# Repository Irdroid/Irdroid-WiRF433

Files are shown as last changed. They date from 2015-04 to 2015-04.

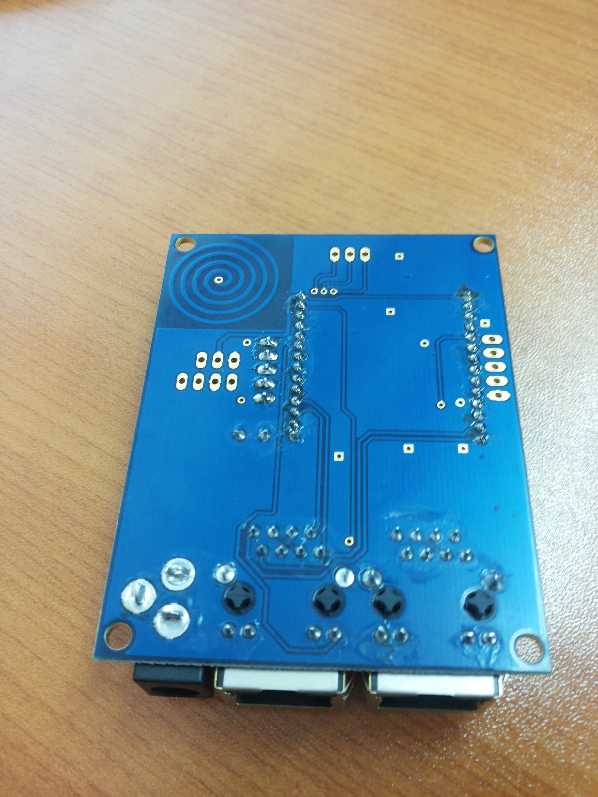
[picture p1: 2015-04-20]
Documents/Pictures & Screenshots/Irdroid-Wirf433-3.jpg

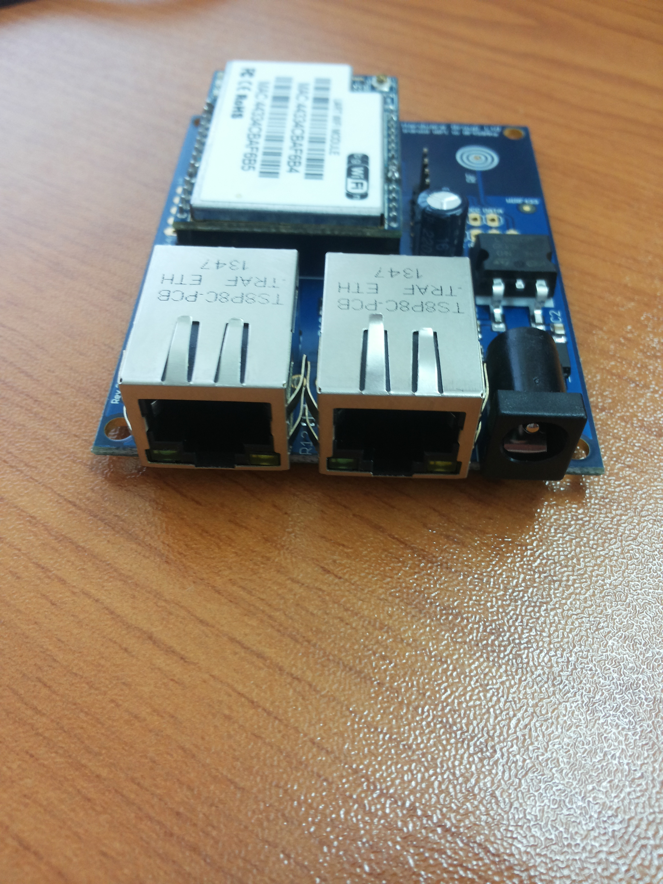
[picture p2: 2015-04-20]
Documents/Pictures & Screenshots/Irdroid-WiRF433-2.jpg

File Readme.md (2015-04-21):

#Irdroid WiRF433 - Single Board Linux Computer, Designed by Hardwate Group Ltd.
------------------------------------------------------------------------------
Irdroid WiRF433 is open source software and open source hardware, low cost starting
from USD 38 Linux Industrial grade single board computer with GPIOs capable to operate 
-25 - +85C

The Irdroid WiRF433 SBC is designed with the Ralink RT5350 SoC, 32Mbytes of RAM and 4 Mbytes of Flash.
The Irdroid WiRF433 board is designed with 2 ethernet ports, therefore the board can be 
used for routing. 

All the GPIOs of the RT5350 Soc are available on the WiRF433 board pin headers. The Irdroid WiRF433
comes also with a RF433MHZ RF module which allows for controlling IoT Remote control switches, light bulbs
and sockets operating at 433.9Mhz.

Irdroid WiRF433 is completely open source - including hardware and software, this means you have 
access to all CAD files and sources and you can reuse them for your own personal or commercial project.
There are NO restrictions to manufacture and sell these board for your own use or resale.

###Main Features:
- Mips Architecture CPU @360Mhz
- 32 Mbytes of SDRAM
- 4 Mbyets of FLASH memory
- 1 USB 2.0 HOST Port
- 1-SPI, 1-I2C , and on I2S (AUDIO)
- WiFi 802.11b/g/n interface
- 2 Ethernet interfaces 1WAN and 1LAN
- RF433 RF Remote control interface with onboard Antenna

The Irdroid WiRF433 SBC comes with preinstalled uboot bootloader and OpenWRT Linux distribution, which includes
also IoT remote control applications and software like RCSwitch for controlling RC 433.9Mhz remote control
switches and a Mobile HTML5 web application , configured for work with the RC switches, which gives the possibility to add unlimited number of RCSwitches

###APPLICATIONS:
- Home Automation Development Computer. The Open Source apps like LIRC,RCSwitch and serial web proxy will allow you to rapidly and easyly build Home Automation Systems
- IoT Development Computer. With its available interfaces, you can turn Irdroid WiRF433 into a IoT main unit, and you will be able to control RC Switches, RC Lights and RC Sockets
- Internet Router with IoT capabilities - The OpenWRT open source Linux distributions will allow you to easyly create one
- Inexpensive PLC with the open source protocols, available on the Internet.

###WEB RESOURCES:
- http://www.irdroid.com - The Irdroid project website, where Irdroid WiRF433 board info is hosted
- http://github.com/irdroid - Project's Github repositories.
- http://www.irdroid.eu/product/irdroid-wifi-rf433mhz-development-computer/ - Currently you can purchase a sample board from irdroid.eu for 38$

###HARDWARE
The Hardware project is released under the Creative Commons Attribution-Share Alike 3.0 United States License. You may reproduce it for both your own personal use, and for commertial use. You will have to provide a link to the original creator of the project http://www.irdroid.com on any documentation or website.
You may also modify the files, but you must then release them as well under the same terms.Credit can be attributed through a link to the creator website: http://www.irdroid.com

###SOFTWARE
The Irdroid WiRF433 Development board comes with preinstalled uboot bootloader and the OpenWRT Linux distribution. The board also comes with the following preinstalled applications:
- RCSwitch for controlling RF433Mhz remote control sockets, lights and switches
- Web Based HTML5 Interface for RCSwitch

The software is released under GPL.

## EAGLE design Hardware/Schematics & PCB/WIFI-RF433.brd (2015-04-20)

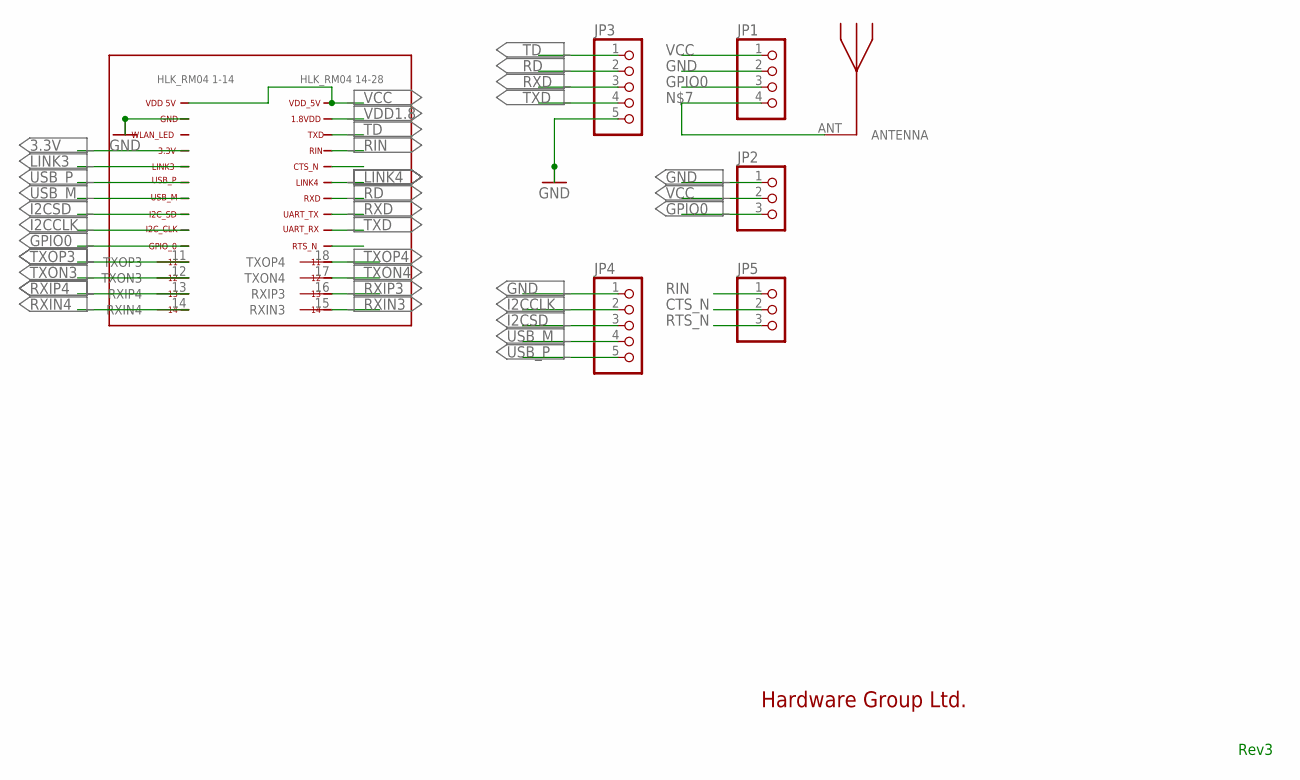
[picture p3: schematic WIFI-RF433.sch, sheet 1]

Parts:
JP1: PINHD-1X4; 1X04
JP2, JP5: PINHD-1X3; 1X03
JP3, JP4: PINHD-1X5; 1X05
U$4: 433MHZ
U$8: 1X10

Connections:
3.3V: U$8.4 (3.3VDD)
CTS_N: JP5.2, U$8.24 (CTS_N)
GND: JP1.2, JP2.1, JP3.5, JP4.1, U$8.2 (GND); also elsewhere on the board
GPIO0: JP1.3, JP2.3, U$8.10 (GPIO_0)
I2CCLK: JP4.2, U$8.9 (I2C_CLK)
I2CSD: JP4.3, U$8.8 (I2C_SD)
LINK3: U$8.5 (LINK3); also elsewhere on the board
LINK4: U$8.23 (LINK4); also elsewhere on the board
unnamed: JP1.4, U$4.ANT
RD: JP3.2, U$8.22 (RXD)
RIN: JP5.1, U$8.25 (RIN)
RTS_N: JP5.3, U$8.19 (RTS_N)
RXD: JP3.3, U$8.21 (UART_TX)
RXIN3: U$8.15 (RXIN3); also elsewhere on the board
RXIN4: U$8.14 (RXIN4); also elsewhere on the board
RXIP3: U$8.16 (RXIP3); also elsewhere on the board
RXIP4: U$8.13 (RXIP4); also elsewhere on the board
TD: JP3.1, U$8.26 (TXD)
TXD: JP3.4, U$8.20 (UART_RX)
TXON3: U$8.12 (TXON3); also elsewhere on the board
TXON4: U$8.17 (TXON4); also elsewhere on the board
TXOP3: U$8.11 (TXOP3); also elsewhere on the board
TXOP4: U$8.18 (TXOP4); also elsewhere on the board
USB_M: JP4.4, U$8.7 (USB_M)
USB_P: JP4.5, U$8.6 (USB_P)
VCC: JP1.1, JP2.2, U$8.1 (VDD_5V), U$8.28 (VDD_5V_); also elsewhere on the board
VDD1.8: U$8.27 (1.8VDD); also elsewhere on the board

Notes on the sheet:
Hardware Group Ltd.
Rev3

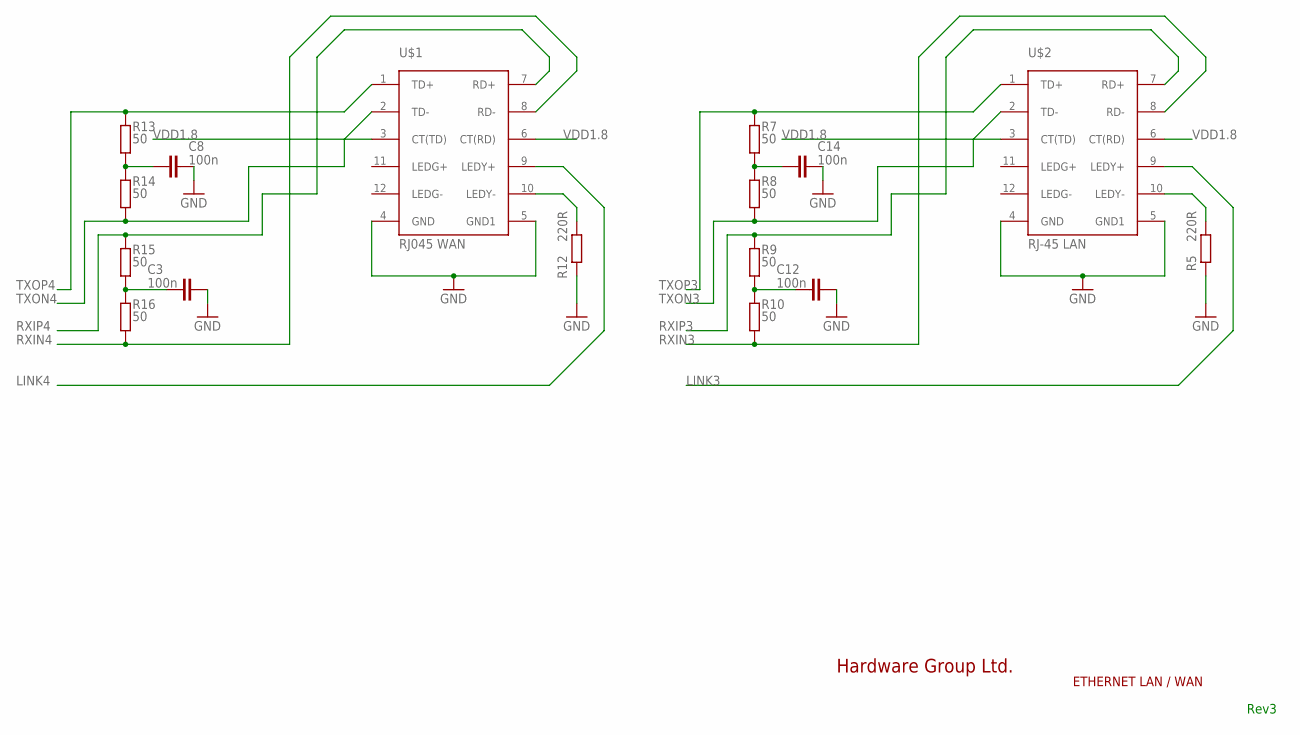
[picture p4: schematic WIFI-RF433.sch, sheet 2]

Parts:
C3, C8, C12, C14: 100n; C0805
R5, R12: 220R; R0805
R7, R8, R9, R10, R13, R14, R15, R16: 50; R0805
U$1: RJ045 WAN; MAGJACK
U$2: RJ-45 LAN; MAGJACK

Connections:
GND: C3.2, C8.2, C12.2, C14.2, R5.1, R12.1, U$1.4 (GND), U$1.5 (GND1), U$2.4 (GND), U$2.5 (GND1); also elsewhere on the board
LINK3: U$2.9 (LEDY+); also elsewhere on the board
LINK4: U$1.9 (LEDY+); also elsewhere on the board
unnamed: R5.2, U$2.10 (LEDY-)
unnamed: C3.1, R15.1, R16.2
unnamed: R12.2, U$1.10 (LEDY-)
unnamed: C8.1, R13.1, R14.2
unnamed: C14.1, R7.1, R8.2
unnamed: C12.1, R9.1, R10.2
RXIN3: R10.1, U$2.8 (RD-); also elsewhere on the board
RXIN4: R16.1, U$1.8 (RD-); also elsewhere on the board
RXIP3: R9.2, U$2.7 (RD+); also elsewhere on the board
RXIP4: R15.2, U$1.7 (RD+); also elsewhere on the board
TXON3: R8.1, U$2.2 (TD-); also elsewhere on the board
TXON4: R14.1, U$1.2 (TD-); also elsewhere on the board
TXOP3: R7.2, U$2.1 (TD+); also elsewhere on the board
TXOP4: R13.2, U$1.1 (TD+); also elsewhere on the board
VDD1.8: U$1.3 (CT(TD)), U$1.6 (CT(RD)), U$2.3 (CT(TD)), U$2.6 (CT(RD)); also elsewhere on the board

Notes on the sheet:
Hardware Group Ltd.
ETHERNET LAN / WAN
Rev3

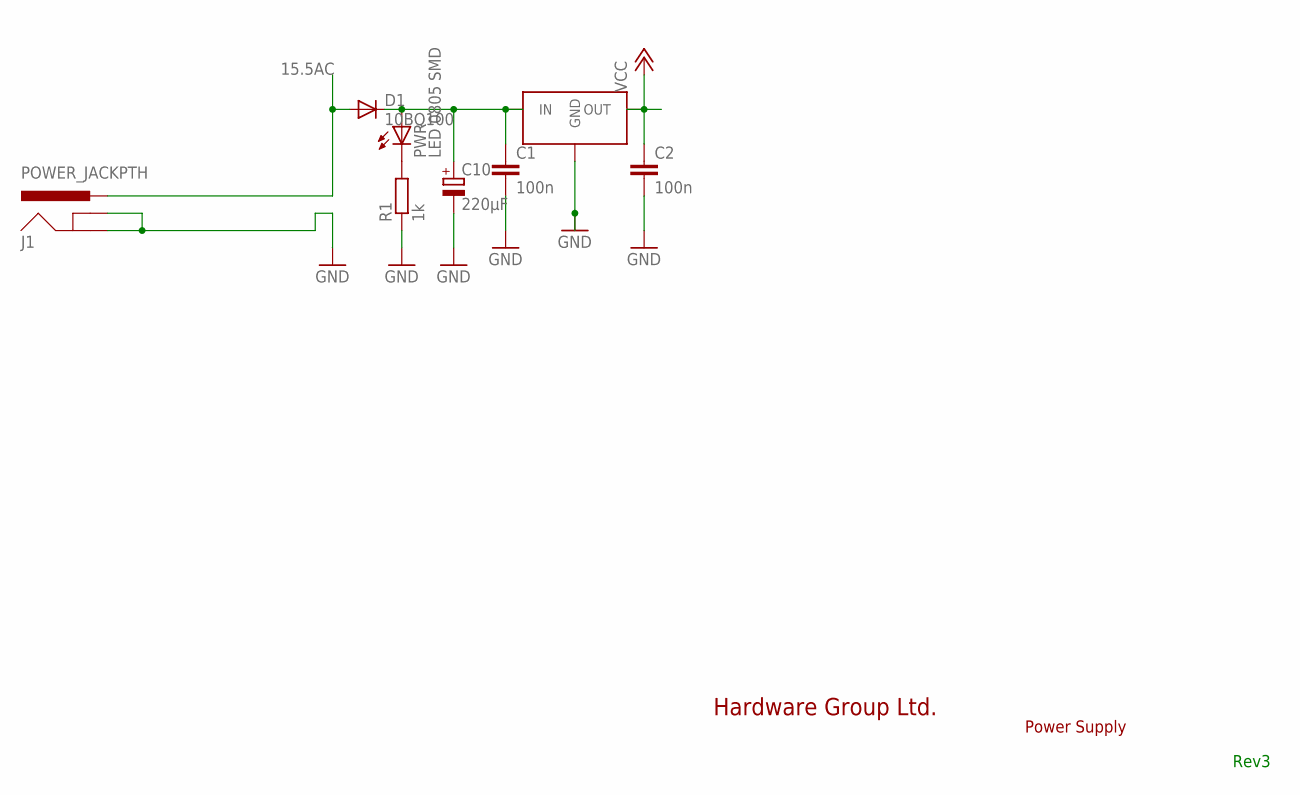
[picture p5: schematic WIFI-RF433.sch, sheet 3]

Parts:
C1, C2: 100n; C0805
C10: 220µF; E3,5-8
D1: 10BQ100; SMB
J1: POWER_JACKPTH; POWER_JACK_PTH
PWR: LED 0805 SMD; CHIP-LED0805
R1: 1k; M0805
U$3: VREG-7805-DPAK2

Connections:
15.5AC: D1.A, J1.PWR
GND: C1.2, C2.2, C10.-, J1.GND, J1.GNDBREAK, R1.1, U$3.GND; also elsewhere on the board
unnamed: PWR.C, R1.2
unnamed: C1.1, C10.+, D1.C, PWR.A, U$3.VIN (IN)
VCC: C2.1, U$3.VOUT (OUT); also elsewhere on the board

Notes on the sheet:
Hardware Group Ltd.
Power Supply
Rev3

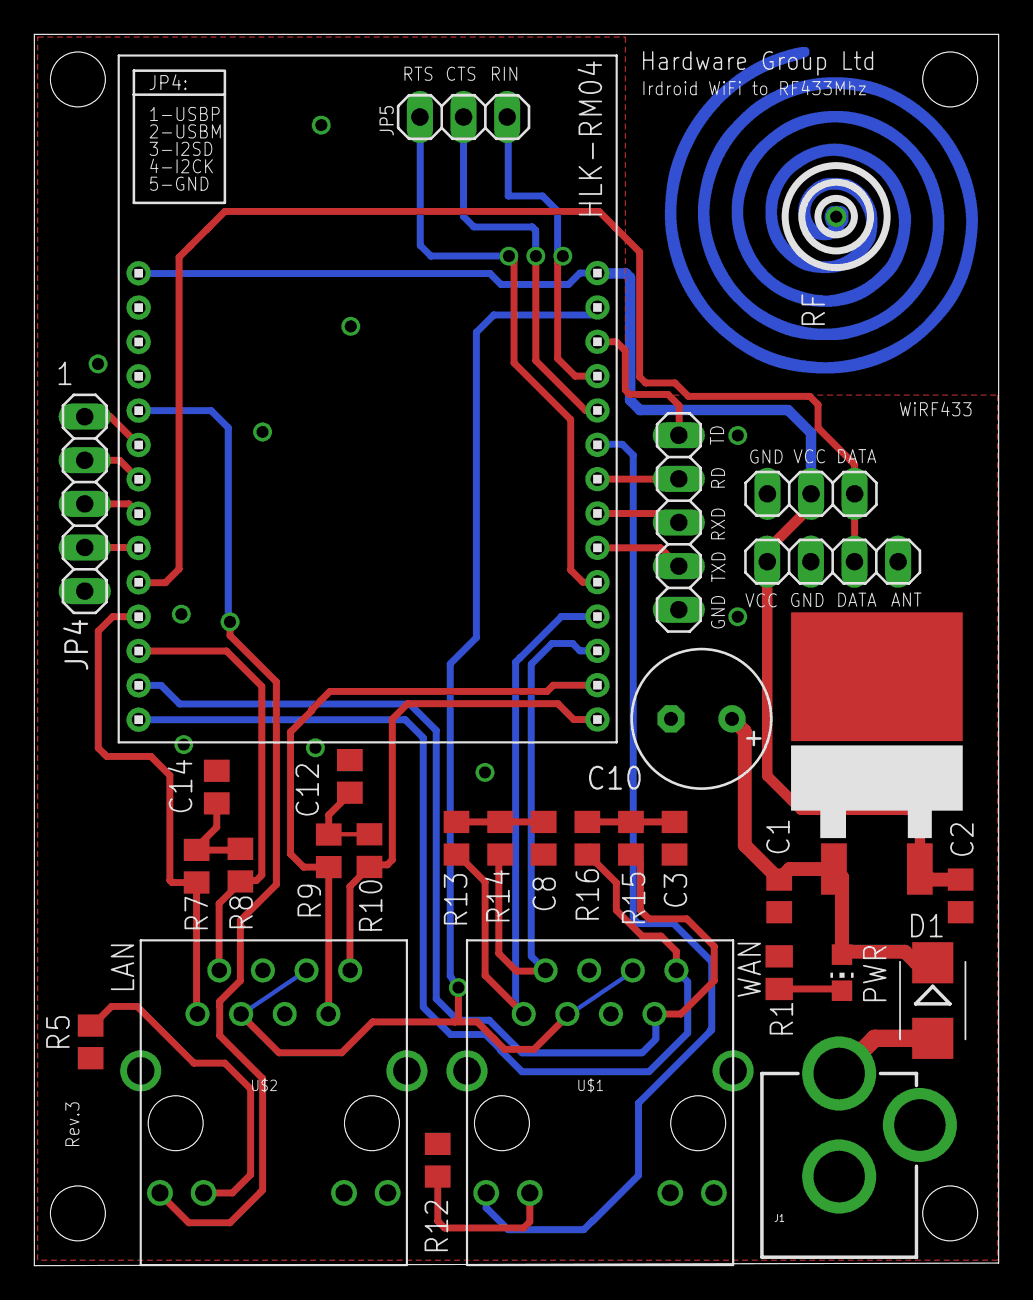
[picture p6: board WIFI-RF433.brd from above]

Board: 2 copper layers, 56.2 x 71.7 mm, 31 parts (0 on the bottom side), 35 nets.

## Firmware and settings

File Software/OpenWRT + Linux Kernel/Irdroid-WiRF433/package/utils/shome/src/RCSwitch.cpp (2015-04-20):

/*
  RCSwitch - Arduino libary for remote control outlet switches
  Copyright (c) 2011 Suat Özgür.  All right reserved.
  
  Contributors:
  - Andre Koehler / info(at)tomate-online(dot)de
  - Gordeev Andrey Vladimirovich / gordeev(at)openpyro(dot)com
  - Skineffect / http://forum.ardumote.com/viewtopic.php?f=2&t=48
  
  Project home: http://code.google.com/p/rc-switch/

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
  You should have received a copy of the GNU Lesser General Public
  License along with this library; if not, write to the Free Software
  Foundation, Inc., 51 Franklin St, Fifth Floor, Boston, MA  02110-1301  USA
*/

#include "RCSwitch.h"
#include <stdio.h>
#include <string.h>
#include <stdlib.h>
unsigned long RCSwitch::nReceivedValue = NULL;
unsigned int RCSwitch::nReceivedBitlength = 0;
unsigned int RCSwitch::nReceivedDelay = 0;
unsigned int RCSwitch::nReceivedProtocol = 0;
unsigned int RCSwitch::timings[RCSWITCH_MAX_CHANGES];
int RCSwitch::nReceiveTolerance = 60;

RCSwitch::RCSwitch() {
//  this->nReceiverInterrupt = -1;
  this->nTransmitterPin = 0;
//  RCSwitch::nReceivedValue = NULL;
//  this->setPulseLength(timer);
//  this->setRepeatTransmit(40);
//  this->setReceiveTolerance(60);
  this->setProtocol(1);
}

/**
  * Sets the protocol to send.
  */
void RCSwitch::setProtocol(int nProtocol) {
  this->nProtocol = nProtocol;
  if (nProtocol == 1){
//	  this->setPulseLength(timer);
  }
  else if (nProtocol == 2) {
//	  this->setPulseLength(650);
  }
}
void digitalWrite(int led, int state) {
FILE *f1;


f1 = fopen ("/sys/class/gpio/gpio0/value", "w");
fprintf (f1, "%d", state);
fclose (f1);
}
void pinMode(int pin, int state) {
FILE *f1;
f1 = fopen ("/sys/class/gpio/export", "w");
fprintf (f1, "%d", pin);
fclose (f1);





f1 = fopen ("/sys/class/gpio/gpio0/direction", "w");
fprintf (f1, "out");
fclose (f1);

digitalWrite(pin, 0);
}
void delayMicrosecondsHard (unsigned int howLong)
{
  struct timeval tNow, tLong, tEnd ;

  gettimeofday (&tNow, NULL) ;
  tLong.tv_sec = howLong / 1000000 ;
  tLong.tv_usec = howLong % 1000000 ;
  timeradd (&tNow, &tLong, &tEnd) ;

  while (timercmp (&tNow, &tEnd, <))
    gettimeofday (&tNow, NULL) ;
}

void delayMicroseconds (unsigned int howLong)
{
  struct timespec sleeper ;

  /**/ if (howLong == 0)
    return ;
  else if (howLong < 100)
    delayMicrosecondsHard (howLong) ;
  else
  {
    sleeper.tv_sec = 0 ;
    sleeper.tv_nsec = (long)(howLong * 1000) ;
    nanosleep (&sleeper, NULL) ;
  }
}

/**
  * Sets the protocol to send with pulse length in microseconds.
  */
void RCSwitch::setProtocol(int nProtocol, int nPulseLength) {
  this->nProtocol = nProtocol;
  if (nProtocol == 1){
	  this->setPulseLength(nPulseLength);
  }
  else if (nProtocol == 2) {
	  this->setPulseLength(nPulseLength);
  }
}


/**
  * Sets pulse length in microseconds
  */
void RCSwitch::setPulseLength(int nPulseLength) {
  this->nPulseLength = nPulseLength;
}

/**
 * Sets Repeat Transmits
 */
void RCSwitch::setRepeatTransmit(int nRepeatTransmit) {
  this->nRepeatTransmit = nRepeatTransmit;
}

/**
 * Set Receiving Tolerance
 */
void RCSwitch::setReceiveTolerance(int nPercent) {
  RCSwitch::nReceiveTolerance = nPercent;
}
  

/**
 * Enable transmissions
 *
 * @param nTransmitterPin    Arduino Pin to which the sender is connected to
 */
void RCSwitch::enableTransmit(int nTransmitterPin) {
  this->nTransmitterPin = nTransmitterPin;
  pinMode(1, OUTPUT);
}

/**
  * Disable transmissions
  */
void RCSwitch::disableTransmit() {
  this->nTransmitterPin = -1;
}

/**
 * Switch a remote switch on (Type C Intertechno)
 *
 * @param sFamily  Familycode (a..f)
 * @param nGroup   Number of group (1..4)
 * @param nDevice  Number of device (1..4)
  */
void RCSwitch::switchOn(char sFamily, int nGroup, int nDevice) {
  this->sendTriState( this->getCodeWordC(sFamily, nGroup, nDevice, true) );
}

/**
 * Switch a remote switch off (Type C Intertechno)
 *
 * @param sFamily  Familycode (a..f)
 * @param nGroup   Number of group (1..4)
 * @param nDevice  Number of device (1..4)
 */
void RCSwitch::switchOff(char sFamily, int nGroup, int nDevice) {
  this->sendTriState( this->getCodeWordC(sFamily, nGroup, nDevice, false) );
}

/**
 * Switch a remote switch on (Type B with two rotary/sliding switches)
 *
 * @param nAddressCode  Number of the switch group (1..4)
 * @param nChannelCode  Number of the switch itself (1..4)
 */
void RCSwitch::switchOn(int nAddressCode, int nChannelCode) {
  this->sendTriState( this->getCodeWordB(nAddressCode, nChannelCode, true) );
}

/**
 * Switch a remote switch off (Type B with two rotary/sliding switches)
 *
 * @param nAddressCode  Number of the switch group (1..4)
 * @param nChannelCode  Number of the switch itself (1..4)
 */
void RCSwitch::switchOff(int nAddressCode, int nChannelCode) {
  this->sendTriState( this->getCodeWordB(nAddressCode, nChannelCode, false) );
}

/**
 * Switch a remote switch on (Type A with 10 pole DIP switches)
 *
 * @param sGroup        Code of the switch group (refers to DIP switches 1..5 where "1" = on and "0" = off, if all DIP switches are on it's "11111")
 * @param nChannelCode  Number of the switch itself (1..4)
 */
void RCSwitch::switchOn(char* sGroup, int nChannel) {
  this->sendTriState( this->getCodeWordA(sGroup, nChannel, true) );
}

/**
 * Switch a remote switch off (Type A with 10 pole DIP switches)
 *
 * @param sGroup        Code of the switch group (refers to DIP switches 1..5 where "1" = on and "0" = off, if all DIP switches are on it's "11111")
 * @param nChannelCode  Number of the switch itself (1..4)
 */
void RCSwitch::switchOff(char* sGroup, int nChannel) {
  this->sendTriState( this->getCodeWordA(sGroup, nChannel, false) );
}
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

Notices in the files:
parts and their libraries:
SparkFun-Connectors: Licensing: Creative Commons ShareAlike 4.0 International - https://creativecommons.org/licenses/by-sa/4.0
